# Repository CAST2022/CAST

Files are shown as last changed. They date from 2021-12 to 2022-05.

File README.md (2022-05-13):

# CAST
## Executive Summary
Our covid sanitization robot will bridge the gap between the need for clean surfaces and the lack of workforce brought about by different circumstances. Our robot will utilize a gamepad controller to move and Lidar as an early warning system of moving obstacles. To sanitize surfaces, we have a robotic arm equipped with UV lights that kill bacteria upon exposure and three time of flight sensors that will take in proximity data and maintain a safe distance between the arm and the surface to be cleaned. 

To allow the user to test the effectiveness of the robot we are also creating a bacteria killed indicator. This indicator uses a UV sensor to measure the amount of UV C radiation absorbed by the area and has the capabilities to communicate using IOT. By incorporating this product, we are giving the user an ability to test the effectiveness of the robot, this will be useful for error detection. 

By incorporating lidar into our design we’re paving the way for the robot to be fully autonomous in the future, removing the need for the gamepad controller. With a fully autonomous robot the design will be able to clean a small area without human interaction.

## Most Recent Github
https://github.com/kennethgrau/CAST_BACKUP

## Directories
To view the Hardware CAD models, one must have a CAD modeling program that SUPPORTS .SLDPRT

The Software is split into two sections. The first section is the Robots Software, that is run on a Raspberry Pi. It uses Python coding to control the system. The second section is the UV Sensor, it uses an Ardiuno Nano and is controlled by C++ codes.

## Special Thanks
The team would like to start off by thanking everyone that has helped us get to this point in our project. Specifically, Dr. Biswas, David Malawey, Donald Bowen, Brey Carawey, Jorge Roa, Ricardo Castillo, Matthew Hammond, and Dr. Crosby. We’d also like to extend our thanks to the Texas A&M ETID department for the time and funding put into ensuring we have all the resources we need to complete this project.

## License
This work is licensed under the Creative Commons Attribution-ShareAlike 4.0 License. To view details visit [creativecommons.org](https://creativecommons.org/licenses/by-sa/4.0/legalcode)

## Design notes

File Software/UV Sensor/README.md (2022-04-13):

# CAST Software - UV Sensor

This contains all the software used on our Capstone Team's UV Sensor. When the UV lights reaches a certain threshold on the sensor, the Ardiuno will flash a green light. In the scenario where the UV lights has not reached the threshold, the Ardiuno will flash red.

## Data to Support values used in Code

Below shows two different documentations that provide the evidence for data used in the code.

[Gidari-2021-Sars-cov--survival-on-surfaces-and-.pdf](https://github.com/CAST2022/CAST/files/8485068/Gidari-2021-Sars-cov--survival-on-surfaces-and-.pdf)

The document above states "Based on our results, a smaller dose of UV-C (10.25–23.71 mJ/cm2) is enough to reduce the viral titer of >99.99%." Meaning 23.71 mJ/cm2 would cover every type of surface covid may appear on. 
If a user knows the specific type of surface the sensor will be placed on, the value can be changed to reflect that type of surface.

https://cdn-shop.adafruit.com/datasheets/1918guva.pdf

The specifications sheet above shows the conversions needed to get the input converted to UV intensity.

## Sensor Data

The following file shows the UV sensor data from a panel of 5 UV-C LEDs in the 265 nm range.

[UV.Sensor.Test.Values.docx](https://github.com/CAST2022/CAST/files/8485109/UV.Sensor.Test.Values.docx)

## License
This work is licensed under the Creative Commons Attribution-ShareAlike 4.0 License. To view details visit [creativecommons.org](https://creativecommons.org/licenses/by-sa/4.0/legalcode)

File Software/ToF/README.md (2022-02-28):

# CAST Software - Vl53l0x ToF Sensor

This contains all the software for programming the ToF sensors

## Installation

Be sure to install the adafruit bus device before running the program

```bash
sudo pip3 install adafruit-circuitpython-busdevice
```
Make sure to download [adafruit_vl53l0x.py](https://github.com/CAST2022/CAST/blob/Master/Software/ToF/adafruit_vl53l0x.py) in the same folder before running the program

## Program References
[Adafruit_CircuitPython_Vl53l0x](https://github.com/adafruit/Adafruit_CircuitPython_VL53L0X)

## License
This work is licensed under the Creative Commons Attribution-ShareAlike 4.0 License. To view details visit [creativecommons.org](https://creativecommons.org/licenses/by-sa/4.0/legalcode)

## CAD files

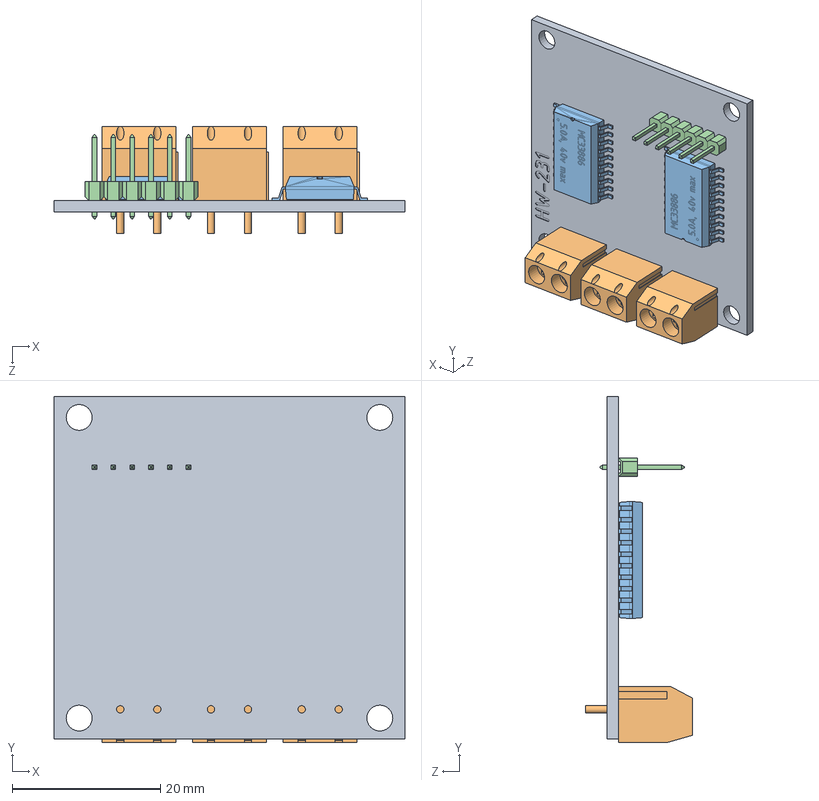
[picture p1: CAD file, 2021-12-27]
Hardware/SOLIDWORKSComposer/MotorDriver.SLDASM
47.4 x 46.8 x 14.5 mm
MotorDriverHW321
ScrewTerminal x 4
hBridge x 2
pinHeader1x6

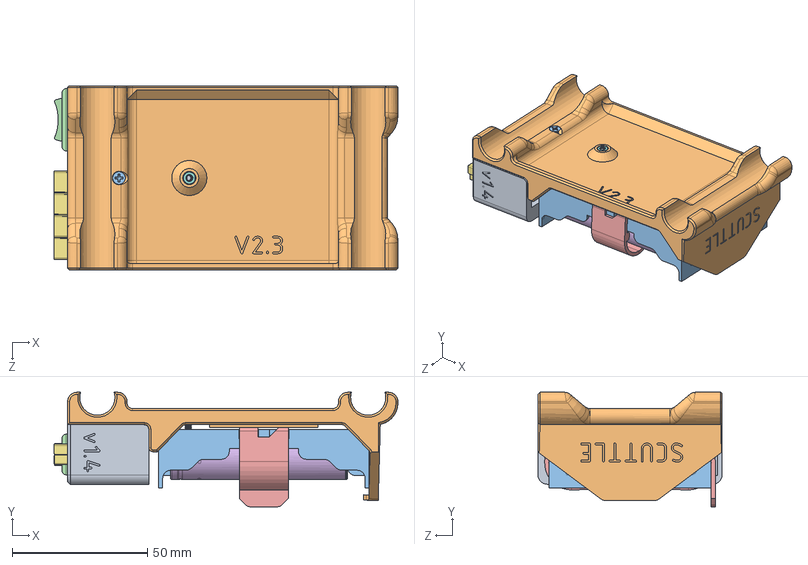
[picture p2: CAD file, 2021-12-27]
Hardware/SOLIDWORKSComposer/batteryPanelAssem.SLDASM
127.0 x 42.3 x 68.0 mm
batPanel
batMount v2.3
batTray
switchSRB22
batHoop
batCell x 3
powerpoleConnector x 4
insertM2.5x3.4
screw M2.5x8
batPCB
screw m2.5x10 csk x 3

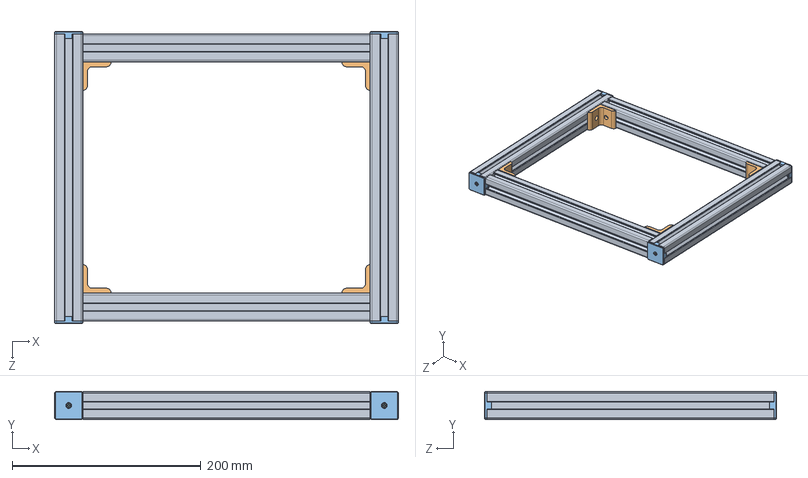
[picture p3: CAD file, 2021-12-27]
Hardware/SOLIDWORKSComposer/Chassis.SLDASM
364.8 x 30.0 x 309.8 mm
tSlot 30mm x 4
bracket30mm x 4
endCap x 4
screw m2.5x6 csink x 4

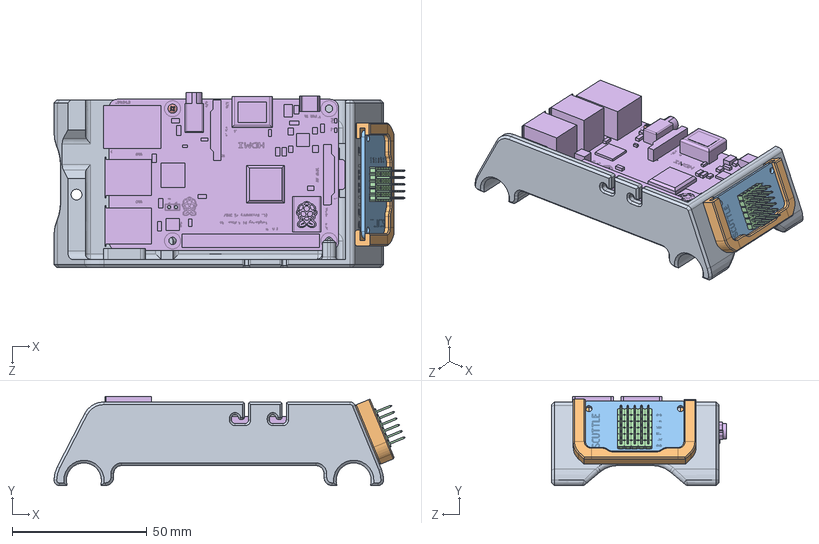
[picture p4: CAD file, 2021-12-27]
Hardware/SOLIDWORKSComposer/Assem Beagle.SLDASM
130.1 x 33.0 x 64.8 mm
BeagleMount V2
i2cBracket v2
circuitBoardi2c v1
pinHeaderDupont x 5
screw M2 plastic
Ras Pi 3B+

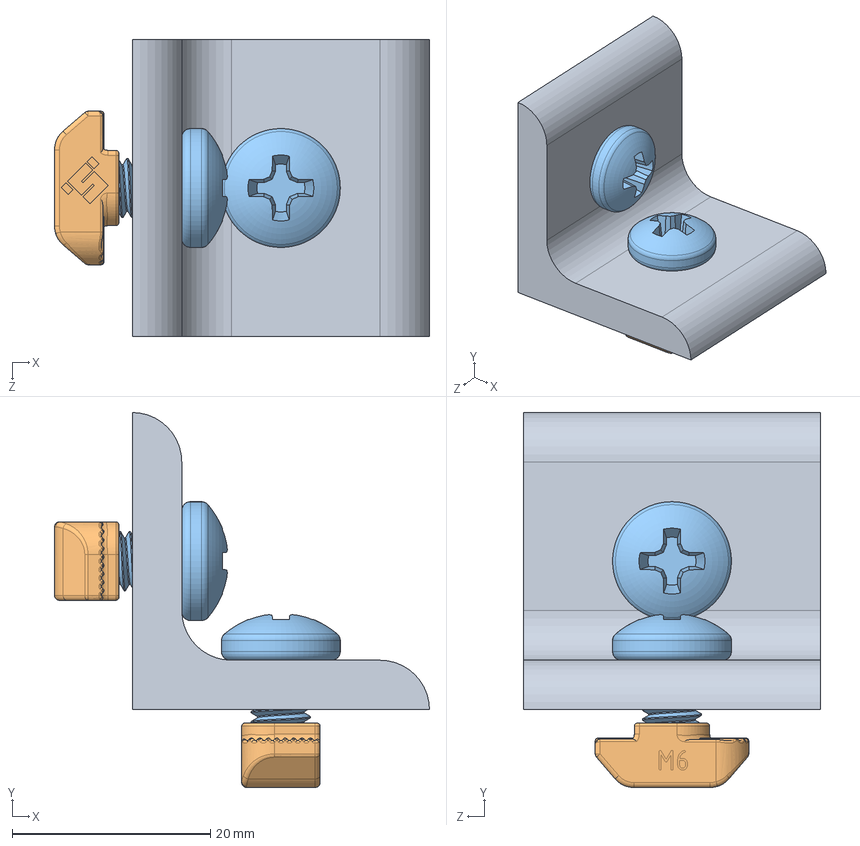
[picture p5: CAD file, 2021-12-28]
Hardware/New T Slot Bracket.SLDASM
37.8 x 37.8 x 30.0 mm
bracket30mm
nut M6 tslot x 2
screw M6x12 ph x 2

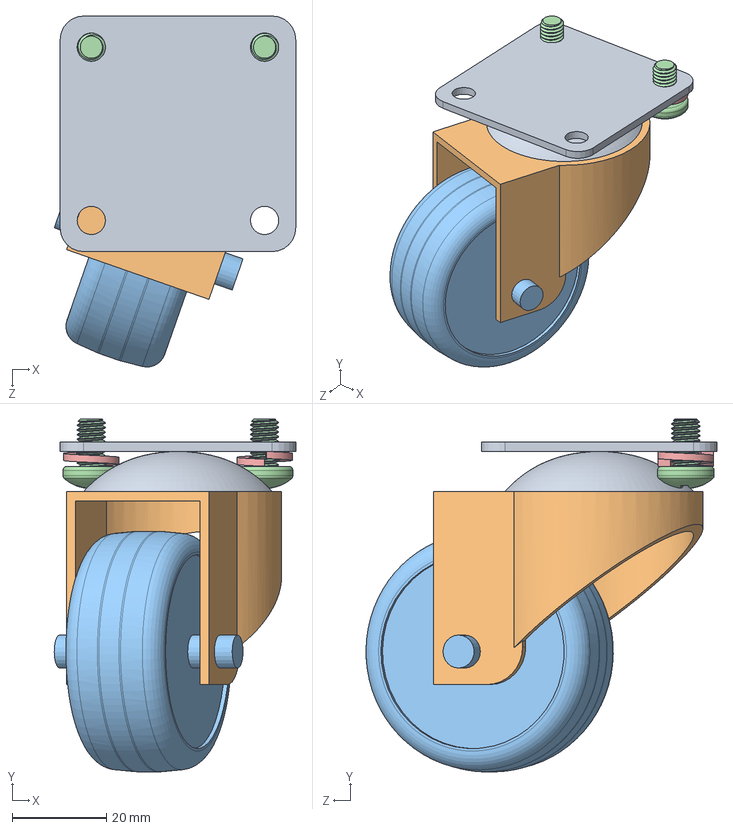
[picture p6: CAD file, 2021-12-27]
Hardware/SOLIDWORKSComposer/caster.SLDASM
51.3 x 74.8 x 74.5 mm
casterPlate
casterCarrier
casterWheel
screw M6x10 ph x 2
washer, lock M6 x 2

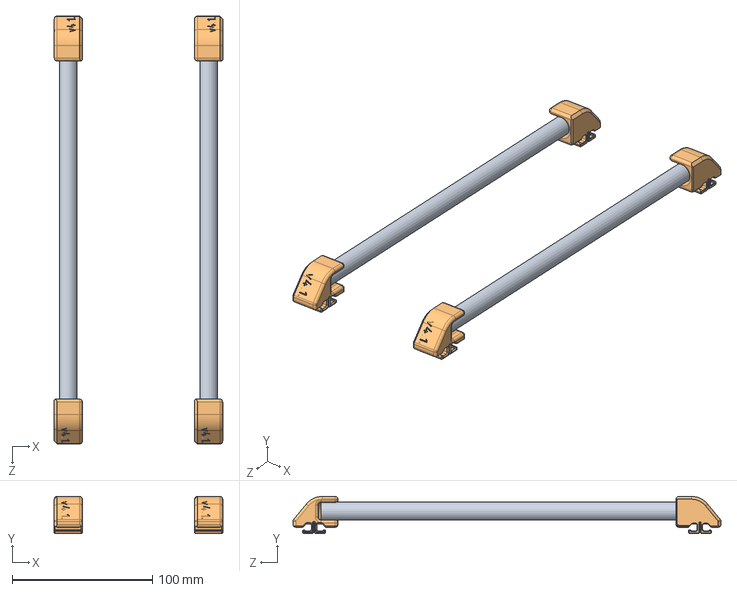
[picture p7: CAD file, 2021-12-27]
Hardware/SOLIDWORKSComposer/rodAssy.SLDASM
120.0 x 26.5 x 304.8 mm
tube 12.7mm x 2
rodBracket v4 x 4

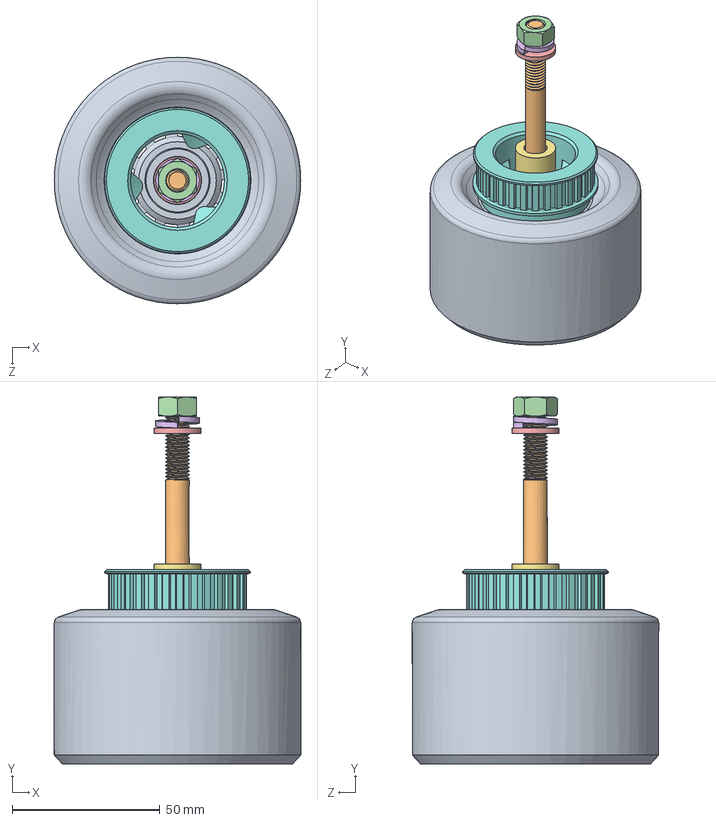
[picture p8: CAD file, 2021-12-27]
Hardware/SOLIDWORKSComposer/AssemWheel.SLDASM
83.5 x 124.3 x 83.5 mm
ballBearing608 v1 x 2
Screw M8x110 axle
Spacer, bearing v1
M8 hex nut-1
Washer M8, Flat
Washer, M8 lock
wheelSpacer v1
wheelPulley v2
wheel

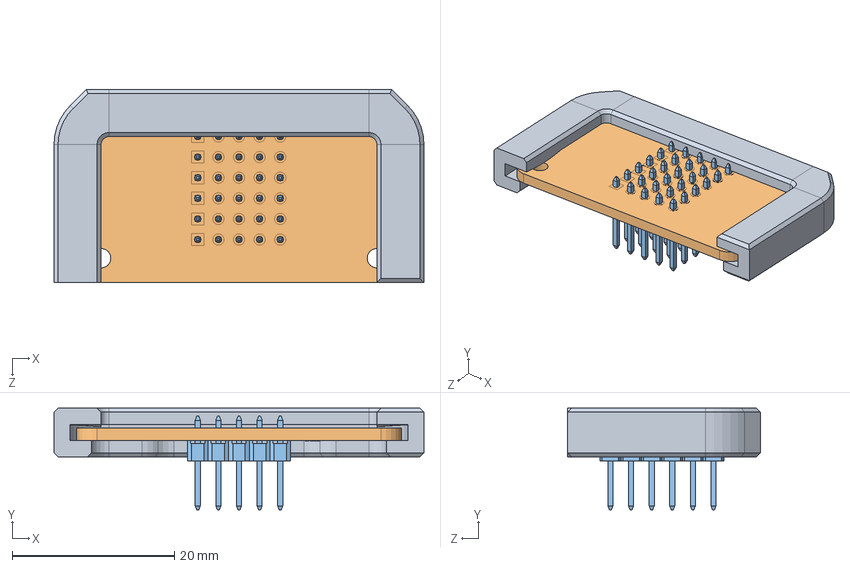
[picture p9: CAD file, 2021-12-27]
Hardware/SOLIDWORKSComposer/i2C_Breakout_ASSY.SLDASM
45.6 x 12.5 x 23.8 mm
i2cBracket v2
circuitBoardi2c v1
pinHeaderDupont x 5

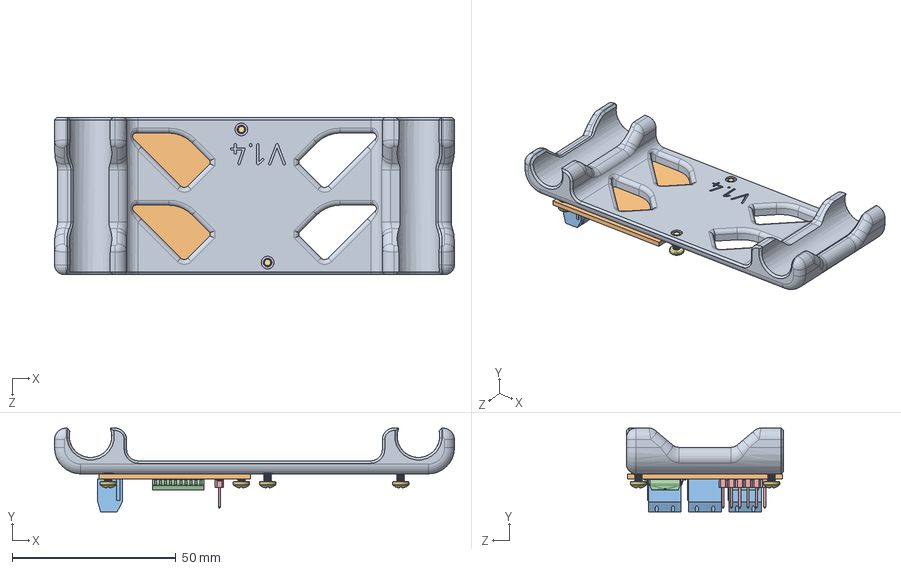
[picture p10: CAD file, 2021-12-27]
Hardware/SOLIDWORKSComposer/dualMotorDriverAssy.SLDASM
122.0 x 25.6 x 48.0 mm
DualMotorDriverMount
MotorDriverHW321
ScrewTerminal x 4
hBridge x 2
pinHeader1x6
ThreadedInsert x 4
ScrewM2.5x6 x 4

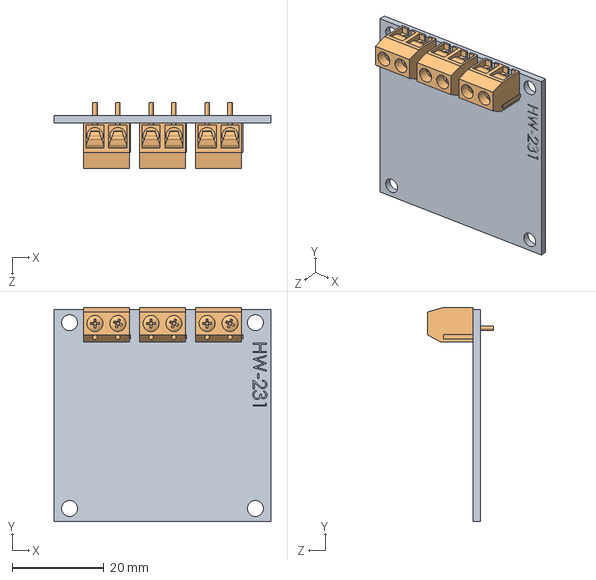
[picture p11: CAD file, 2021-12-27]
Hardware/SOLIDWORKSComposer/driverHW231.SLDASM
47.4 x 46.8 x 14.5 mm
MotorDriverHW321
ScrewTerminal x 4

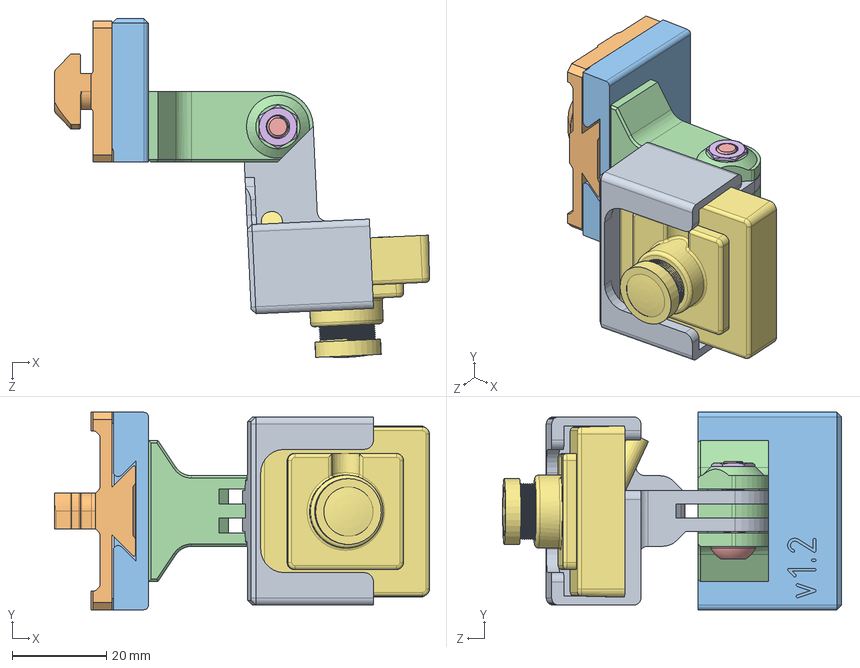
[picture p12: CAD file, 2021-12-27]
Hardware/SOLIDWORKSComposer/camera assembly.SLDASM
79.7 x 42.0 x 72.0 mm
SqCamBrk
twistBracket V3b
doveTailF v1
goProPlain v1.0
screw m5x18
nut m5
squareCam

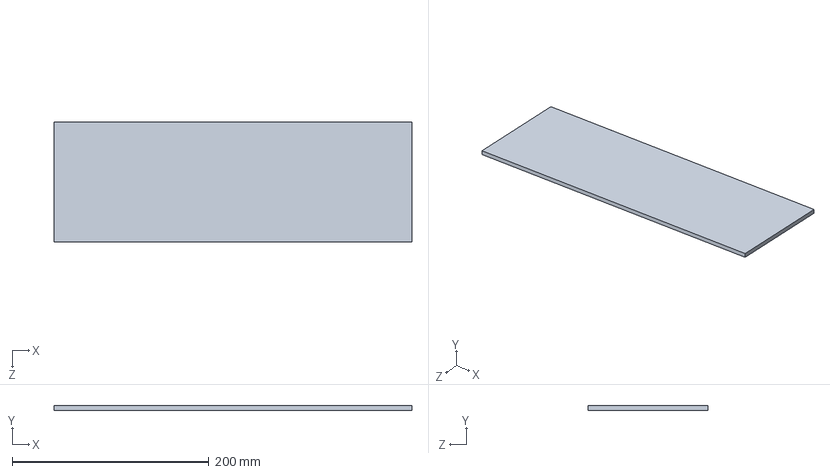
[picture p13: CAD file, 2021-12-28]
Hardware/14.33 by 4.8 in cover for sides of base.SLDPRT
364.0 x 4.76 x 122.0 mm

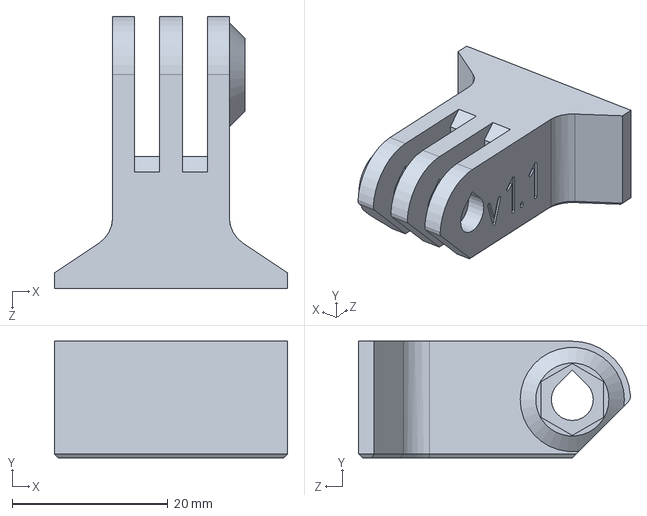
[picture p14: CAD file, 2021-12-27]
Hardware/SOLIDWORKSComposer/goProPlain v1.0.SLDPRT
30.0 x 15.0 x 35.0 mm

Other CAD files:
Hardware/M3 Pan Head 6mm.SLDPRT
Hardware/SOLIDWORKSComposer/encoderBracketV2.SLDPRT
Hardware/SC8LUU Double Bearing Mount.SLDPRT
Hardware/SOLIDWORKSComposer/batMount v2.3.SLDPRT
Hardware/12 by 3.54 in cover.SLDPRT
Hardware/12 by 6 in cover.SLDPRT
Hardware/12.17 by 3.54 in cover.SLDPRT
Hardware/12.17 by 6 in cover.SLDPRT
Hardware/17.93 by 7.28 in cover.SLDPRT
Hardware/19.93 by 7.28 in cover.SLDPRT
Hardware/37.65 by 7.28 in cover.SLDPRT
Hardware/46.31 by 7.28 in cover.SLDPRT
Hardware/47.31 by 7.28 in cover.SLDPRT
Hardware/4mm x 14mm Allen Hex Nut.SLDPRT
Hardware/5 to 8mm x 19mm x 25mm Shaft Coupler.SLDPRT
Hardware/5537T736 12.86 inches.SLDPRT
Hardware/5537T736 124.79mm 4 15 16 in.SLDPRT
Hardware/5537T736 184.8mm 7 1 4 in.SLDPRT
Hardware/5537T736 20.9 in.SLDPRT
Hardware/5537T736 244.79mm.SLDPRT
Hardware/5537T736 496.9 mm 19 9 16 in.SLDPRT
Hardware/5537T736 498.64 mm 19 5 8 in.SLDPRT
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

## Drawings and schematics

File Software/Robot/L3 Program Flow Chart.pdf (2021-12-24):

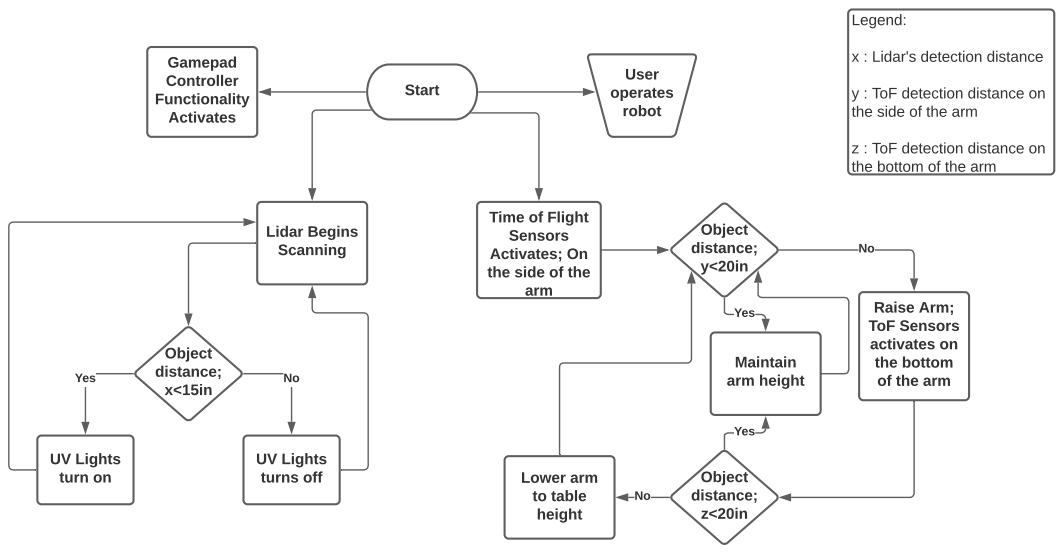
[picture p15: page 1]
Start; Gamepad Controller Functionality Activates; Object distance; x<15in; UV Lights turn on; UV Lights turns off; Yes; User operates robot; Lidar Begins Scanning; Object distance; y<20in; Object distance; z<20in; Lower arm to table height; Maintain arm height; Legend:

x : Lidar's detection distance

y : ToF detection distance on
the side of the arm

z : ToF detection distance on
the bottom of the arm

Time of Flight
Sensors
Activates; On
the side of the
arm

Raise Arm;
ToF Sensors
activates on
the bottom
of the arm

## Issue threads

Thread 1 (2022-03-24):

Validate cardboard lidar cover

dmalawey, 2022-03-24:
Let's review LIDAR measurements.
1) Can we get an explanation of how the Lidar samples are taken as of 2/34?
2) Please share how your prototype cover is used, and why this is necessary at this stage.
3) Please add a link to the file which control the lidar samples

Reference [youtube test video](https://youtu.be/A6CPlSUSw1E?list=PLxU24ZnFDi6z1EAg5RTBa9gfiPB4_u0_O)

Edgar-Mac, 2022-03-25:
1. I have left comments on the updated Lidar program to further explain the programs functionality.
2. The cover is used to provide control walls for the lidar. We know the distance of the walls from the lidar so we filter out those values, in turn eliminating the viewpoints we are not interested in at this stage. This allows us to obtain distance data from front of the lidar, where the table will be read, with minimum potential for faulty readings.
3. [Lidar Sample Controller](https://github.com/CAST2022/CAST/blob/Master/Software/Robot/L2_lidar.py)

- Edgar Macias
- CAST - System Integration Engineer

dmalawey, 2022-03-30:
We need your explanation of how the lidar readings angles are defined, and what they mean when the lidar unit is mounted on your robot.   I have added questions to [your video](https://photos.app.goo.gl/eoudZqrW8TdNx4zt5)

kennethgrau, 2022-04-14:
Confirmed lidar angles are defined according to the diagram below. Output from our L1 code will be a 360 item array where the index is theta and values are distance readings. From there the readings can be processed further.

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

That being said, I think we can get rid of the "reference walls"

Closed 2022-04-14.

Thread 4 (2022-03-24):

UV Sensor FOV

donaldb1226, 2022-03-24:
During the demonstration, the UV LEDs had to be directly above the sensor to function properly. We need to have the sensor's FOV roughly measured to know the optimal angles at which the sensor is placed. This will guide us further down the line when we are using these sensors in a real-world environment.

CAST2022, 2022-03-25:
[UV Sensor Test Values.docx](https://github.com/CAST2022/CAST/files/8346671/UV.Sensor.Test.Values.docx)
 Test values for UV Sensor, this shows distance and angles

Closed 2022-03-25.

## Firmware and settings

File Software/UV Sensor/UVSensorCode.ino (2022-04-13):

//Test UV Sensor and what value we get from UV Light
//UV Dose needs to reach:
const int UVDoseRequirement = 15; // 15 mJ/cm^2 is the UV dose needed for bacteria on most surfaces

//Ports for lights
const int red = 5;
const int green = 4;

const int numReadings = 200;//Number of readings to get 
float readings = 0;      // the readings from the analog input
int readIndex = 0;              // the index of the current reading
int total = 0;                  // the running total
float Average = 0;                // the average
//counters
int MainCounter = 0;
int Reset = 0;
int Finished = 0;

//sensor values
float UVDose;
float smoothing();


void setup()
{
  // initialize LEDs as an output.
  pinMode(red, OUTPUT);
  pinMode(green, OUTPUT);
  Serial.begin(9600);
}

void loop()
{
  //loop to signify UV is in area. Under 300 uW/cm^2 indicates no UV
  while (Average < 300 && Finished != 1)
  {
    smoothing(); //input function

    //Red LED on and Green Off. Initial Stage
    digitalWrite(green, LOW);   // turn the Green LED off
    digitalWrite(red, HIGH);   // turn the LED on (HIGH is the voltage level)
    //Delay one second
    delay(1000);

    //Add one second to reset counter
    Reset += 1;
    //if the reset counter hits 30 seconds, it resets the main counter
    if (Reset >= 30)
    {
      MainCounter = 0;
    }
  }

  while (Average >= 300 && Finished != 1) //300 uW/cm^2 is the minimum for UV intensity to blink green LED
  {
    smoothing();
    Reset = 0;
    //red LED turns off and green blinks to signify that area is being cleaned.
    digitalWrite(red, LOW);   // turn the LED off
    digitalWrite(green, HIGH);   // turn the Green LED on
    delay(500);
    digitalWrite(green, LOW);   // turn the Green LED off
    delay(500);
    MainCounter += 1;
    UVDose = (MainCounter * Average)/1000;//divide by 1000 to convert to mJ/cm^2

    if (UVDose > UVDoseRequirement) //When value is reached, the code stays on green on.
    {
      Finished = 1;
      break;
    }
  }

  if (Finished == 1)
  {
    digitalWrite(green, HIGH);   // turn the Green LED on
  }
}

float smoothing()
{
  total = 0;
  for (int count = 0; count < 199; count++)
  {
    readings = analogRead(A0)-2; //Reading inputs, subtractting to offset noise
    readings = readings*50;
    //multiply by 5 because the responisivity at around 260nm is 1/5 for this sensor. Multiply by 10 to convert to uW, as per the spec sheet
    total = total + readings; //total readings together
  }
  // calculate the average, Converts Photocurrent Value to UV Intensity, uW/cm^2 (1uA = 9 mW/cm^2), as per spec sheet
  Average = ((total / numReadings) * 9);
  return (Average);
}

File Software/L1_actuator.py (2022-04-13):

# L1 program for CAST Bot actuator runnning SCUTTLE RasPi image
# This code sends signals to ST-M5045 motor driver/NEMA 23 stepper motor on appropriate GPIO pins
# See wiring guide doncument for pin mapping
# Last update 04.12.2022 - Kenneth Grau

# Import external libraries

# note pigpio uses BROADCOM numbers for labeling
import pigpio

# sleep is used for precision stepping as timing has a resolution of 1ms
import time
from time import sleep

# Initialize pigpio
pi = pigpio.pi()

# label signal pins
puls = 13
dir = 19
en = 26

# Label endstop pins
topEndStop = 5
botEndStop = 6

# Setup mode for GPIO pins
pi.set_mode(puls, pigpio.OUTPUT)            # pulse/signal generation
pi.set_mode(dir, pigpio.OUTPUT)             # direction pin
pi.set_mode(en, pigpio.OUTPUT)              # enable pin (active low)
pi.set_mode(topEndStop, pigpio.INPUT)       # enable pin (active low)
pi.set_mode(botEndStop, pigpio.INPUT)       # enable pin (active low)


# Set of parameters preset by user determined by actuator and driver
linearDistancePerRev = 0.00508  # lead as specified by actuator ball screw datasheet (m)
stepsPerRev = 800               # steps per revolution per driver
maxPrecisionSpeed = 0.00635
maxSpeed = 0.09525


# Move arm in a specified direct at specified speed with precision stepping
def stepMove(dist, dirs, speed = maxPrecisionSpeed):
    
    pi.set_mode(puls, pigpio.OUTPUT)                        # Ensure pin is in correct mode and setup enable
    pi.write(en,0)
    
    if (dirs == 1):                                         # Set direction based on input
        pi.write(dir,1)
    else:
        pi.write(dir,0)
    
    steps = dist / linearDistancePerRev * stepsPerRev       # Calculate steps needed to travel desired distance
    
    delay = 1/(speed/linearDistancePerRev*stepsPerRev)/2    # Calculate delay for desired speed
    
    for x in range(int(steps)):
        pi.write(puls,0)
        sleep(delay)
        pi.write(puls,1)
        sleep(delay)
        
    pi.write(en,1)
            
# Move the arm in direction with specified speed (less precise but much faster)
def pwmMove(dist, dirs, speed = maxSpeed):
    
    pi.write(en,0)
    x = 0
    
    if (dirs == 1):                                     # Set direction based on input
        pi.write(dir,1)
    else:
        pi.write(dir,0)
    
    freq = speed / linearDistancePerRev * stepsPerRev   # Calculate frequency for desired speed
    
    delay = (dist / speed) + (freq / 100 * 0.001)       # Calculate wait for certain distance
    if (delay < 0):
        delay = 0
    
    while(x <= freq):                                   # Ramp up to speed (maybe replace with log ramping)
        pi.hardware_PWM(puls,x,50000)
        sleep(0.001)
        x = x + 100
    time.sleep(delay)                                   # Let pwm drive for certain amount of time
    
    pi.hardware_PWM(puls, 0, 0)                         # Turn off PWM
    pi.write(en,1)
        
# Reset actuator arm to bottom position
def resetArm():

    pi.write(en,0)
    pi.write(dir,0)
    x = 0
    
    while(x <= 15000):                                  # Ramp up to speed (maybe replace with log ramping)
        pi.hardware_PWM(puls,x,50000)
        sleep(0.001)
        x = x + 100

# Callback function for handling top endstop trigger       
def topEndStopHandle():

    pi.set_mode(puls, pigpio.OUTPUT)
    pi.write(dir,0)
    pi.write(en,0)
    
    while (pi.read(topEndStop) == 1):                   # Move arm off endstop
        pi.write(puls,0)
        sleep(0.0001)
        pi.write(puls,1)
        sleep(0.0001)
        
    pi.write(en,1)


# Callback function for handling bottom endstop trigger
def botEndStopHandle():

    pi.set_mode(puls, pigpio.OUTPUT)
    pi.write(dir,1)
    
    while (pi.read(botEndStop) == 1):                   # Move arm off endstop
        pi.write(puls,0)
        sleep(0.0001)
        pi.write(puls,1)
        sleep(0.0001)
        
# Setup inturrupts for handling endstops
topStop = pi.callback(5, pigpio.RISING_EDGE, topEndStopHandle)
topStop = pi.callback(6, pigpio.RISING_EDGE, botEndStopHandle)

if __name__ == "__main__":
    
    print('Resetting arm to bottom position...')
    resetArm()
    
    print('Precision move up 1cm')
    stepMove(0.01,1)
    print('Precision move down 1cm')
    stepMove(0.01,0)
    
    print('Speed move up 10cm')
    pwmMove(0.1,1)
    print('Speed move down 10cm')
    pwmMove(0.1,0)

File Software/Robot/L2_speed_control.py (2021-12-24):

# speed_control.py takes target speeds and generates duty cycles
# to send to motors, and has a function to execute PID control.

# Import external libraries
import numpy as np                                  # for handling arrays

# Import local files
from L1Directory import L1_motors as m                               # for controlling motors

# Initialize variables
u_integral = 0
DRS = 0.8                                           # direct rescaling - for open-loop motor duty
kp = 0.04                                           # proportional term
ki = 0.04                                           # integral term
kd = 0.0                                            # derivative term
pidGains = np.array([kp, ki, kd])                   # form an array to collect pid gains.

# a function for converting target rotational speeds to PWMs without feedback
def openLoop(pdl, pdr):
    DRS = 0.8                                       # create a variable for direct-re-scaling
    duties = np.array([pdl, pdr])                   # put the values into an array
    duties = duties * 1/9.75 * DRS                  # rescaling. 1=max PWM, 9.75 = max rad/s achievable
    duties[0] = sorted([-1, duties[0], 1])[1]       # place bounds on duty cycle
    duties[1] = sorted([-1, duties[1], 1])[1]       # place bounds on duty cycle
    return duties

def driveOpenLoop(pdTargets):                       # Pass Phi dot targets to this function
    duties = openLoop(pdTargets[0], pdTargets[1])   # produce duty cycles from the phi dots
    m.MotorL(duties[0])                             # send command to motors
    m.MotorR(duties[1])                             # send command to motors

def scalingFunction(x):                             # a fcn to compress the PWM region where motors don't turn
    if -0.222 < x and x < 0.222:
        y = (x * 3)
    elif x > 0.222:
        y = ((x * 0.778) + 0.222)
    else:
        y = ((x * 0.778) - 0.222)
    return y

def scaleMotorEffort(u):                            # send the control effort signals to the scaling function
    u_out = np.zeros(2)
    u_out[0] = scalingFunction(u[0])
    u_out[1] = scalingFunction(u[1])
    return(u_out)

def driveClosedLoop(pdt, pdc, de_dt):               # this function runs motors for closed loop PID control
    global u_integral
    e = (pdt - pdc)                                 # compute error

    kp = pidGains[0]                                # gains are input as constants, above
    ki = pidGains[1]
    kd = pidGains[2]

    # GENERATE COMPONENTS OF THE CONTROL EFFORT, u
    u_proportional = (e * kp)                                       # proportional term
    try:
        u_integral += (e * ki)                                      # integral term
    except:
        u_integral = (e * ki)                                       # for first iteration, u_integral does not exist

    u_derivative = (de_dt * kd)                                     # derivative term takes de_dt as an argument

    # CONDITION THE SIGNAL BEFORE SENDING TO MOTORS
    u = np.round((u_proportional + u_integral + u_derivative), 2)   # must round to ensure driver handling
    u = scaleMotorEffort(u)                                         # perform scaling - described above
    u[0] = sorted([-1, u[0], 1])[1]                                 # place bounds on the motor commands
    u[1] = sorted([-1, u[1], 1])[1]                                 # within [-1, 1]

    # SEND SIGNAL TO MOTORS
    m.MotorL(round(u[0], 2))                                        # must round to ensure driver handling!
    m.MotorR(round(u[1], 2))                                        # must round to ensure driver handling!
    return
